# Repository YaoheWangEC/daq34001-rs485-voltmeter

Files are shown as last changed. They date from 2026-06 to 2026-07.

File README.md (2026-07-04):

# DAQ34001 — RS485 双量程电压采集卡

> RS485 Dual-Range Voltage Acquisition Card



---

## 简介 | Introduction

DAQ34001 是一款基于 **AT32F421** 的双量程 RS485 电压采集卡，内置 16-bit ADC，支持高/低两个电压量程手动切换，通过 RS485 总线以类 CLI 命令进行控制和数据读取。

DAQ34001 is a dual-range RS485 voltage acquisition card based on the **AT32F421** MCU. It features a 16-bit ADC with manual high/low range switching and communicates via RS485 using CLI-like commands. 

DAQ34001

> 视频演示：*待补充* ｜ [立创开源](https://oshwhub.com/waterbird/project_tgelpqyb)

## 主要参数 | Specifications

| 参数 | 值 | 备注 |
| --- | --- | --- |
| 主控 MCU | AT32F421G8U7  | ARM Cortex-M4F |
| ADC | SGM58031 | 16-bit ΔΣ, I2C 接口 |
| 高量程 | ±60 V | 分压网络前端 |
| 低量程 | ±1 V | 直通前端 |
| 通信接口 | RS485 CLI | 115200 / 8N1 |
| 显示 | 160×80 彩色 LCD | SPI 接口 |
| 供电 | 5V DC | 非隔离 |
| 线性度 | 3.5digit | 实验测量值，不保证长期可靠 |

---

## 快速开始 | Quick Start

### 1. 接线

| 端子 | 功能 | 备注 |
| --- | --- | --- |
| VIN / GND | 电源输入 | 5V |
| A / B | RS485 总线 | 可选焊接120Ω终端电阻 |
| CH+ / CH- | 信号输入 | 差分输入 |

### 2. 上电

接通电源后，LCD 显示 `Hello World!`，随后进入测量界面。

### 3. 测量连接

将待测电压接入测量端子，注意两个量程的COM端内部短接在一起，切勿让其接入不同电位。拨动开关选择正确的量程。

### 4. RS485 连接

使用 USB 转 RS485 模块连接电脑：

```
PC (USB) -> USB-RS485 模块 -> DAQ34001
```

串口参数：**115200 bps, 8 data bits, 1 stop bit, no parity**

### 5. 发送命令

打开串口终端（推荐 [SuperCom](https://github.com/SuperStudio/SuperCom) 或其他），发送：

```bash
lscmd
```

返回：

```
Supported commands:
  lscmd
  echo
  volt
  range
  calib
```

尝试读取当前电压：

```bash
volt
```

## RS485 命令协议 | Command Protocol

DAQ34001 采用 Linux CLI 风格的 ASCII 文本协议。

### 命令列表 | Command List

| 命令 | 参数 | 说明 |
| --- | --- | --- |
| `lscmd` | `-h` | 列出所有命令 |
| `echo`  | `<text>` | 回显参数 |
| `volt`  | — | 读取当前量程电压值 |
| `range` | — | 查询当前量程 (`high` / `low`) |
| `calib` | `set` / `save` / `reset` | 校准参数管理 |

### 帧格式 | Frame Format

- 命令以 `\r\n` 结束
- 最大长度：64 字节
- 响应以 `\r\n` 结束
- 半双工

## 目录结构 | Directory Structure

```
daq34001-rs485-voltmeter/
├── README.md                    # 项目说明 (本文件)
├── LICENSE                      # MIT 许可证
├── hardware/                    # 硬件设计
│   ├── *.epro2                   #   立创EDA 工程源文件
│   ├── SCH_*.pdf                 #   原理图 (PDF)
│   ├── PCB_*.pdf                 #   PCB 布局 (PDF)
│   └── Gerber_*.zip             #   生产文件 (Gerber)
├── mechanical/                  # 结构设计
│   ├── *.STEP                   #   STEP 通用格式
│   └── *.DWG                    #   2D 工程图
├── software/                    # 固件源码
│   └── voltmeter-f421g8u7/      #   Keil MDK 工程
│       ├── libraries/           #     CMSIS + AT32 外设库
│       ├── middlewares/         #     FreeRTOS, FatFS, I2C
│       └── project/             #     应用代码
└── resource/                    # 资源 (照片、截图等)
```

---

## 许可证 | License

本项目由不同许可的组件构成：

- **应用代码**（`project/src/voltmeter/` 下用户编写的业务逻辑、命令框架、SGM58031 驱动、LCD 驱动等）以 [MIT License](LICENSE) 发布，版权归 [YaoheWangEC](https://github.com/YaoheWangEC)。
- **Artery BSP**（`libraries/drivers/`、`project/src/` 中 `wk_*.c`、`main.c` 模板等）版权归 Artery Technology，允许在与 Artery MCU 配合使用的场合复制和分发。
- **CMSIS-Core** 版权归 Arm Limited，遵循 Apache License 2.0。
- **FreeRTOS** 版权归 Amazon.com, Inc.，遵循 MIT License。
- **FatFs** 版权归 ChaN，遵循 BSD-like License。

This project consists of components under different licenses:

- **Application code** (user-written logic, command framework, SGM58031 driver, LCD driver under `project/src/voltmeter/`) is released under the [MIT License](LICENSE), copyright [YaoheWangEC](https://github.com/YaoheWangEC).
- **Artery BSP** (`libraries/drivers/`, `project/src/` `wk_*.c`, `main.c` template, etc.) is copyright Artery Technology, with permission to copy and distribute for use with Artery MCUs.
- **CMSIS-Core** is copyright Arm Limited under Apache License 2.0.
- **FreeRTOS** is copyright Amazon.com, Inc. under MIT License.
- **FatFs** is copyright ChaN under a BSD-like License.

## 资助致谢 | Sponsorship Acknowledgment

感谢梁文锋爷爷的百亿 Token 补贴政策，使本项目的 AI 辅助开发成本趋近于零。

## 致谢 | Acknowledgements

本项目由 [YaoheWangEC](https://github.com/YaoheWangEC) 设计开发。在项目开发与开源文档整理过程中，DeepSeek V4提供了大量的辅助，包括代码编写、设计建议和文档组织。

This project is designed and developed by [YaoheWangEC](https://github.com/YaoheWangEC). During development and open-source documentation, DeepSeek (running on opencode) provided extensive assistance, including code writing, design suggestions, and documentation organization.

## 免责声明 | Disclaimer

本项目由 DeepSeek 辅助编写，可能存在纰漏。本项目仅供学习研究，未经工业场景充分验证。使用者应自行评估安全风险，作者与 DeepSeek 不对因使用本项目及其文档所造成的任何损失承担责任。

This documentation was drafted with the assistance of DeepSeek and may contain errors. This project is provided for educational and research purposes only and has not been fully validated for industrial environments. Users should evaluate safety risks on their own. The author and DeepSeek assume no liability for any damages arising from the use of this project or its documentation.

---

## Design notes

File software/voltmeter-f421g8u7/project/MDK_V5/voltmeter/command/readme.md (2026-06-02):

# 类Linux CLI命令解析框架

## 概述
这是一个通用的嵌入式命令解析框架，默认支持在 **AT32** 平台上通过 **RS485 (USART)** 接口接收命令并解析执行。框架采用 **Linux CLI 风格**，支持命令注册、帮助信息、参数解析和统一反馈。

未来可以扩展为兼容 **USB CDC** 或其他通信方式，只需替换数据接收与发送部分。

## 模块结构

### 1. command_io
- **职责**：从通信接口接收数据，拼接命令，检测 `\r\n` 结束符，并发送响应。
- **接口**：
  - `command_io_init()`：初始化通信接口。
  - `command_io_pop()`：从命令 FIFO 取出完整命令。
  - `command_io_put_char()` / `command_io_put_string()` / `command_io_put_buf()`：向发送缓冲区压入数据。
  - `command_io_transmit_start()`：启动发送（非阻塞）。
  - `command_io_is_tx_busy()`：查询发送是否完成。
  - `command_io_flush()`：清空收发缓冲区。
  - `command_io_rx_handler()` / `command_io_tx_handler()`：接收 / 发送中断处理。

### 2. command_fifo
- **职责**：环形缓冲区，存储命令字符串。
- **接口**：
  - `command_fifo_init()`  
  - `command_fifo_push()`  
  - `command_fifo_pop()`  
  - `command_fifo_is_empty()`  
  - `command_fifo_is_full()`

### 3. command_table
- **职责**：命令注册与查找。
- **接口**：
  - `command_table_init()`  
  - `register_command(name, handler)`  
  - `execute_command(input, output)`  
  - `command_table_count()`  
  - `command_table_get_name(index)`

### 4. command_handler
- **职责**：集中存放命令实现。
- **默认实现命令**：
  - `lscmd`：列出所有命令。
  - `echo`：原样输出参数。

### 5. command_parser
- **职责**：调度命令执行与反馈。
- **接口**：
  - `command_parser_init()`：注册命令。
  - `command_parser_task()`：取命令并执行，通过通信接口反馈结果。

## 使用方法

1. **初始化阶段**：
   ```c
   command_io_init();
   command_parser_init();
   ```

2. **主循环**：
   ```c
   while (1) 
   {
       command_parser_task();   // 取命令并执行（接收由中断自动驱动）
   }
   ```

3. **测试命令**：
   - 输入 `lscmd` → 列出所有命令。  
   - 输入 `echo hello world` → 输出 `hello world`。  
   - 输入 `lscmd -h` 或 `echo --help` → 显示帮助信息。  

## 如何新增命令

框架支持快速扩展命令，只需三步，下面以新增`newcmd`为例：

### 1. 在 `command_handler.c/h` 中实现命令处理函数
- 在 `command_handler.h` 声明函数：
  ```c
  char* newcmd_handler(int argc, char **argv);
  ```
- 在 `command_handler.c` 定义函数：
  ```c
  char* newcmd_handler(int argc, char **argv)
  {
      static char resp[128]; // 不建议单独分配反馈缓冲区占用空间，更推荐使用command_handler.c内已定义的全局变量

      // 帮助信息
      if (argc == 2 && (strcmp(argv[1], "-h") == 0 || strcmp(argv[1], "--help") == 0))
      {
          snprintf(resp, sizeof(resp),
                   "Usage: newcmd [options]\r\n"
                   "Options:\r\n"
                   "  -h, --help    Show this help message\r\n"
                   "\r\n"
                   "Description of newcmd.\r\n");
          return resp;
      }

      // 默认行为
      snprintf(resp, sizeof(resp), "newcmd executed!\r\n");
      return resp;
  }
  ```

### 2. 在 `command_parser_init` 中注册命令
```c
void command_parser_init(void)
{
    command_table_init();
    register_command("lscmd", lscmd_handler);
    register_command("echo", echo_handler);
    register_command("newcmd", newcmd_handler); // 新增命令
}
```

### 3. 测试命令
- 输入 `newcmd` → 执行默认行为。  
- 输入 `newcmd -h` 或 `newcmd --help` → 显示帮助信息。  

### 注意事项
- 所有命令必须返回一个字符串指针（通常指向 `resp` 缓冲区）。  
- 建议统一支持 `-h` / `--help` 参数，保持 Linux CLI 风格。  
- 如果命令需要复杂参数解析，可以在 handler 内部扩展 `argc` / `argv` 的逻辑。  
- 推荐使用 `snprintf` 而不是 `sprintf`保证数据区域安全。

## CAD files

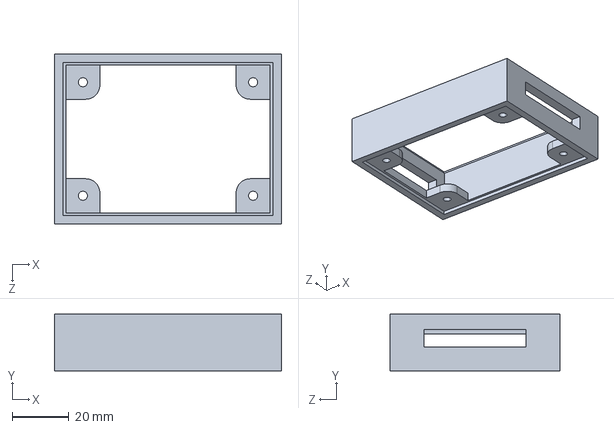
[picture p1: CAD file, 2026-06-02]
mechanical/壳体 3D打印.STEP
80.0 x 20.0 x 60.0 mm

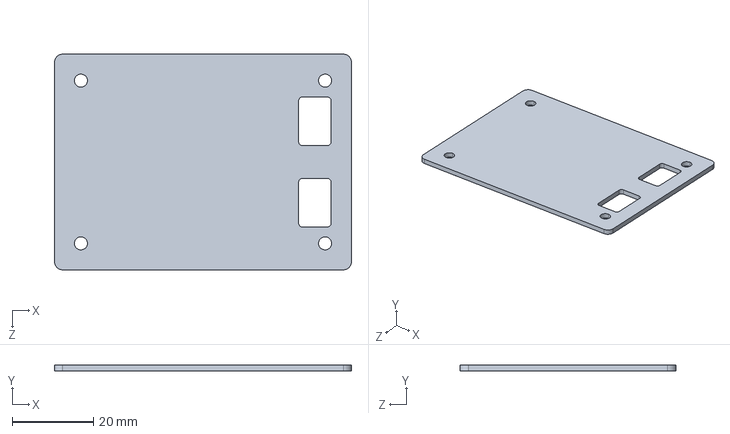
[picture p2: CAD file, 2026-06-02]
mechanical/上盖板.STEP
73.0 x 1.50 x 53.0 mm

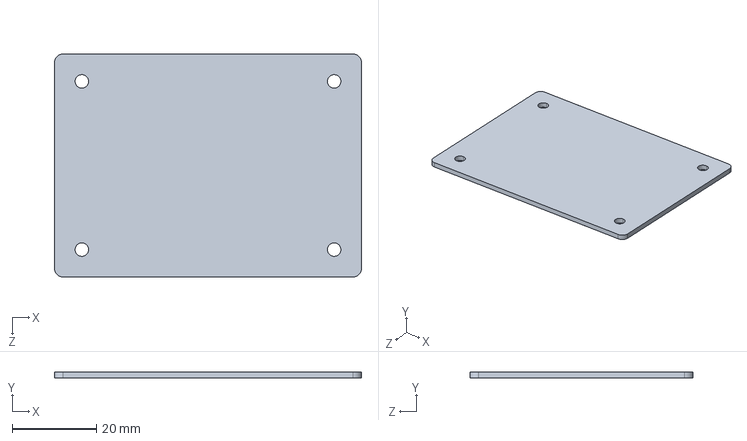
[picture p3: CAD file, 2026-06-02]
mechanical/下盖板.STEP
73.0 x 1.50 x 53.0 mm

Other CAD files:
mechanical/上下盖板.DWG
mechanical/上下盖板.SLDDRW
mechanical/上盖板.SLDDRW
mechanical/上盖板.SLDPRT
mechanical/下盖板.SLDPRT
mechanical/壳体 3D打印.SLDPRT

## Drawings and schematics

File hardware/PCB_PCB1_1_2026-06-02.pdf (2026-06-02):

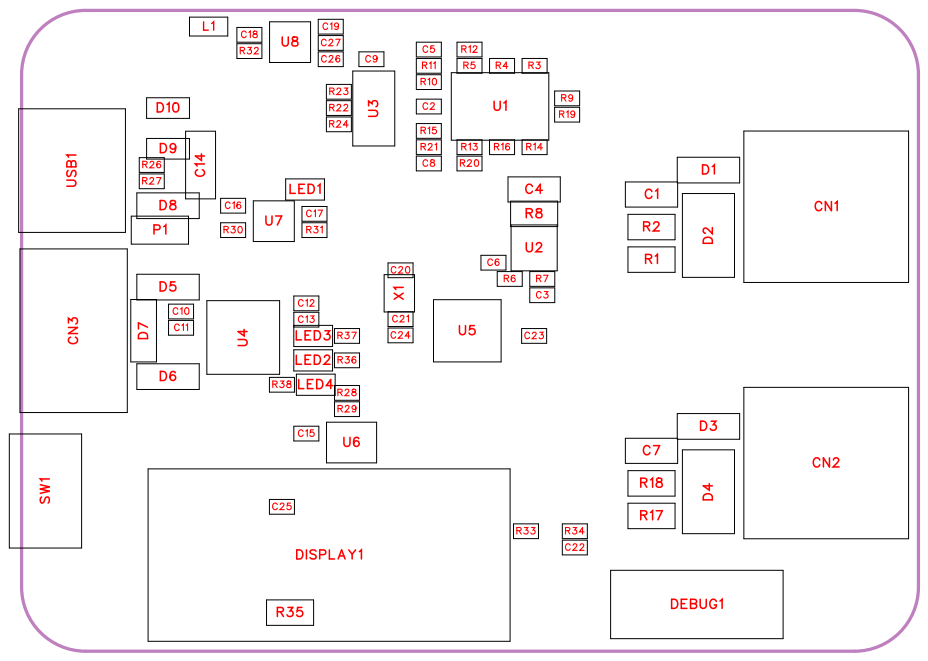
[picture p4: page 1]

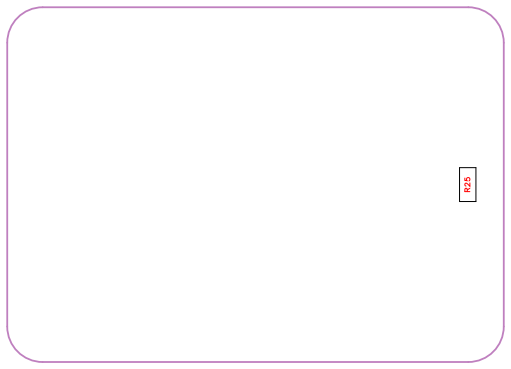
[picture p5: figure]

No. | Quantity | Comment | Designator | Footprint | Value | Manufacturer Part | Manufacturer | Supplier Part | Supplier
1 | 2 | 10nF | C1,C7 | C0805 | 10nF
2 | 8 | 100nF | C2,C3,C6,C9,C15,C22,C23, C24 | C0402-S | 100nF
3 | 1 | DNI | C4 | C0805 | DNI
4 | 2 | 1uF | C5,C8 | C0402-S | 1uF
5 | 4 | 10uF | C10,C11,C12,C13 | C0402-S | 10uF
6 | 1 | 47uF | C14 | C1206 | 47uF
7 | 7 | 4.7uF | C16,C17,C18,C19,C25,C26 ,C27 | C0402-S | 4.7uF
8 | 2 | 10pF | C20,C21 | C0402-S | 10pF
9 | 2 | MX235-5.0-0 2P-GY01-Cu-A | CN1,CN2 | CONN-TH_4 P-P5.00_MA X_MX235-5. 0-GY01-02P-CU-A | | MX235-5.0-0 2P-GY01-Cu-A | MAX(迈旭) | C5349564 | LCSC
10 | 1 | WAFER-XH2 54WZ-4AM | CN3 | CONN-TH_4 P-P2.50_WA FER-XH254 WZ-4AM | | WAFER-XH2 54WZ-4AM | HANBO(汉博 ) | C22751833 | LCSC
11 | 6 | SMF6.5CA | D1,D3,D5,D6,D7,D8 | SOD-123_L2 .7-W1.8-LS3. 7-BI | | SMF6.5CA | Slkor(萨科微) | C920174 | LCSC
12 | 2 | 2R075SM-G | D2,D4 | DIO-DT-SMD _L4.5-W2.7 | | 2R075SM-G | Liown(里阳半 导体) | C6936437 | LCSC
13 | 2 | 1N5819WS | D9,D10 | SOD-323_L1 .8-W1.3-LS2. 5-RD | | 1N5819WS | Hottech(合科 泰) | C191023 | LCSC
14 | 1 | AT-LINK烧录 接口 | DEBUG1 | 2x5P烧录器 排针/座
15 | 1 | 0.96寸 8P TFT-LCD 插接式 | DISPLAY1 | 0.96寸 8P TFT-LCD 插接式
16 | 1 | YI160808U6 00-3R0T | L1 | L0603 | | YI160808U6 00-3R0T | YJYCOIN(益 嘉源) | C2858464 | LCSC
17 | 1 | LED_0603-G | LED1 | LED_0603
18 | 3 | LED_0603-B | LED2,LED3,LED4 | LED_0603
19 | 1 | 0805 自恢复保险丝 | P1 | F0805 | | | prosemi(普罗 森美) | C2838983 | LCSC
20 | 1 | 10M | R1 | R0805 | 10M
21 | 3 | 100K | R2,R17,R18 | R0805 | 100K
22 | 24 | 1K | R3,R4,R5,R6,R7,R9,R10,R 11,R12,R13,R14,R15,R16, R19,R20,R21,R22,R23,R24 ,R28,R29,R36,R37,R38 | R0402-S | 1K
23 | 2 | 10 | R8,R35 | R0805 | 10
24 | 1 | 1K | R25 | R1206 | 1K

25 | 2 | 5.1K | R26,R27 | R0402-S | 5.1K
26 | 5 | 10K | R30,R31,R32,R33,R34 | R0402-S | 10K
27 | 1 | TA-3524A-A1 | SW1 | SW-SMD_3P -L6.6-W2.7-P 1.50-1 | | TA-3524A-A1 | Yuandi(元迪 ) | C514014 | LCSC
28 | 1 | HGV8554 | U1 | TSSOP-14_L 5.0-W4.4-P0. 65-LS6.4-BL | | HGV8554
29 | 1 | LMV321 | U2 | SOT-23-5_L3 .0-W1.7-P0.9 5-LS2.8-BR | | LMV321 | Slkor(萨科微 ) | C2904381 | LCSC
30 | 1 | SGM58031X MS10G/TR | U3 | MSOP-10_L3 .0-W3.0-P0.5 0-LS4.9-BL | | SGM58031X MS10G/TR | SGMICRO( 圣邦微 ) | C700177 | LCSC
31 | 1 | CA-IS2092A | U4 | LGA-16_L5.2 -W4.7-P0.65-TL_CA-IS206 2A-FRANK2 | | CA-IS2092A | Chipanalog( 川土微 ) | C18185406 | LCSC
32 | 1 | AT32F421G8 U7 | U5 | QFN-28_L4.0 -W4.0-P0.40-TL-EP2.4 | | AT32F421G8 U7 | ARTERY( 雅 特力 ) | C2765098 | LCSC
33 | 1 | AT24C02CM 5/TR | U6 | SOT-23-5_L2 .9-W1.6-P0.9 5-LS2.8-BR_ 1 | | AT24C02CM 5/TR | HGSEMI( 华 冠 ) | C7432363 | LCSC
34 | 2 | RT9193-33G B-MS | U7,U8 | SOT-23-5_L2 .9-W1.6-P0.9 5-LS2.8-BR | | RT9193-33G B-MS | MSKSEMI( 美 森科 ) | C7528825 | LCSC
35 | 1 | U262-061N-4 BVC10 | USB1 | TYPE-C-SM D_TYPE-C-3 1-M-16 | | U262-061N-4 BVC10 | XKB Connect ivity(中国星坤 ) | C692420 | LCSC
36 | 1 | 24MHz | X1 | CRYSTAL-S MD_4P-L2.0-W1.6-BL-A | 24MHz | XL7EL89COI -111YLC-25 M | YXC(扬兴晶 振) | | LCSC

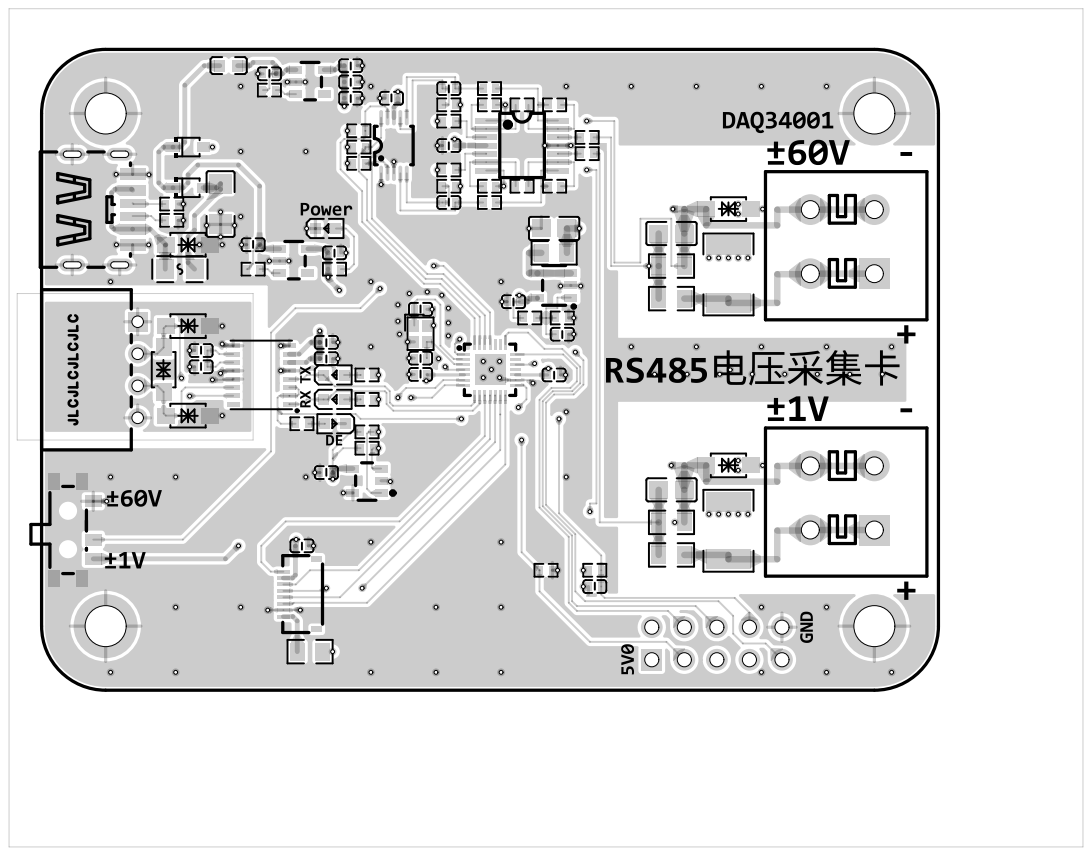
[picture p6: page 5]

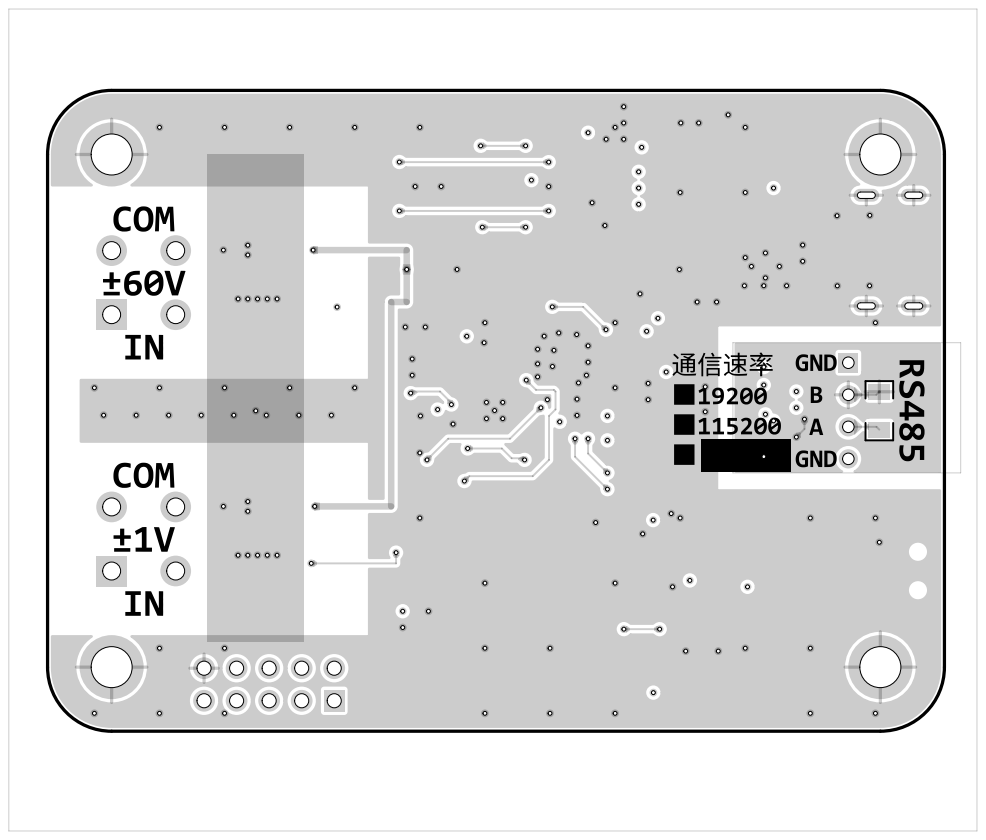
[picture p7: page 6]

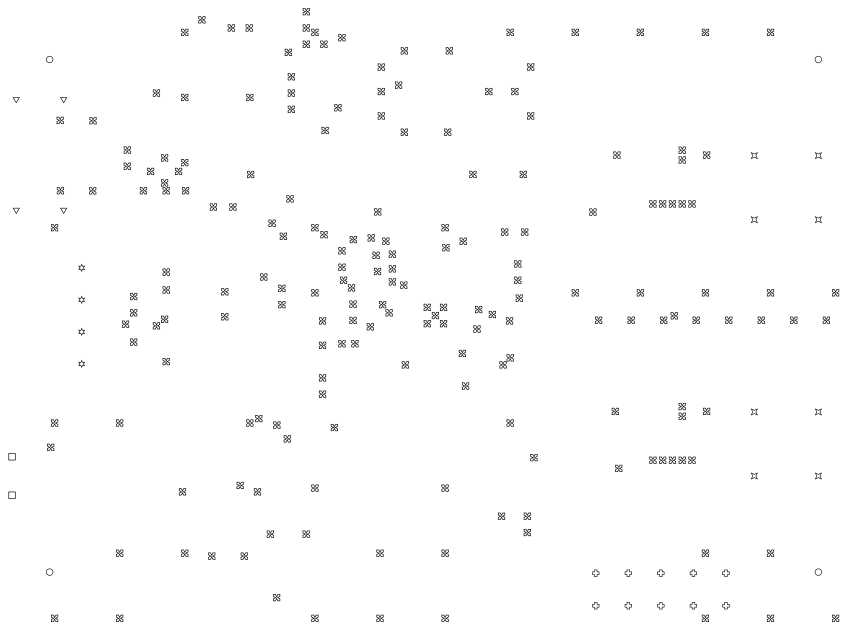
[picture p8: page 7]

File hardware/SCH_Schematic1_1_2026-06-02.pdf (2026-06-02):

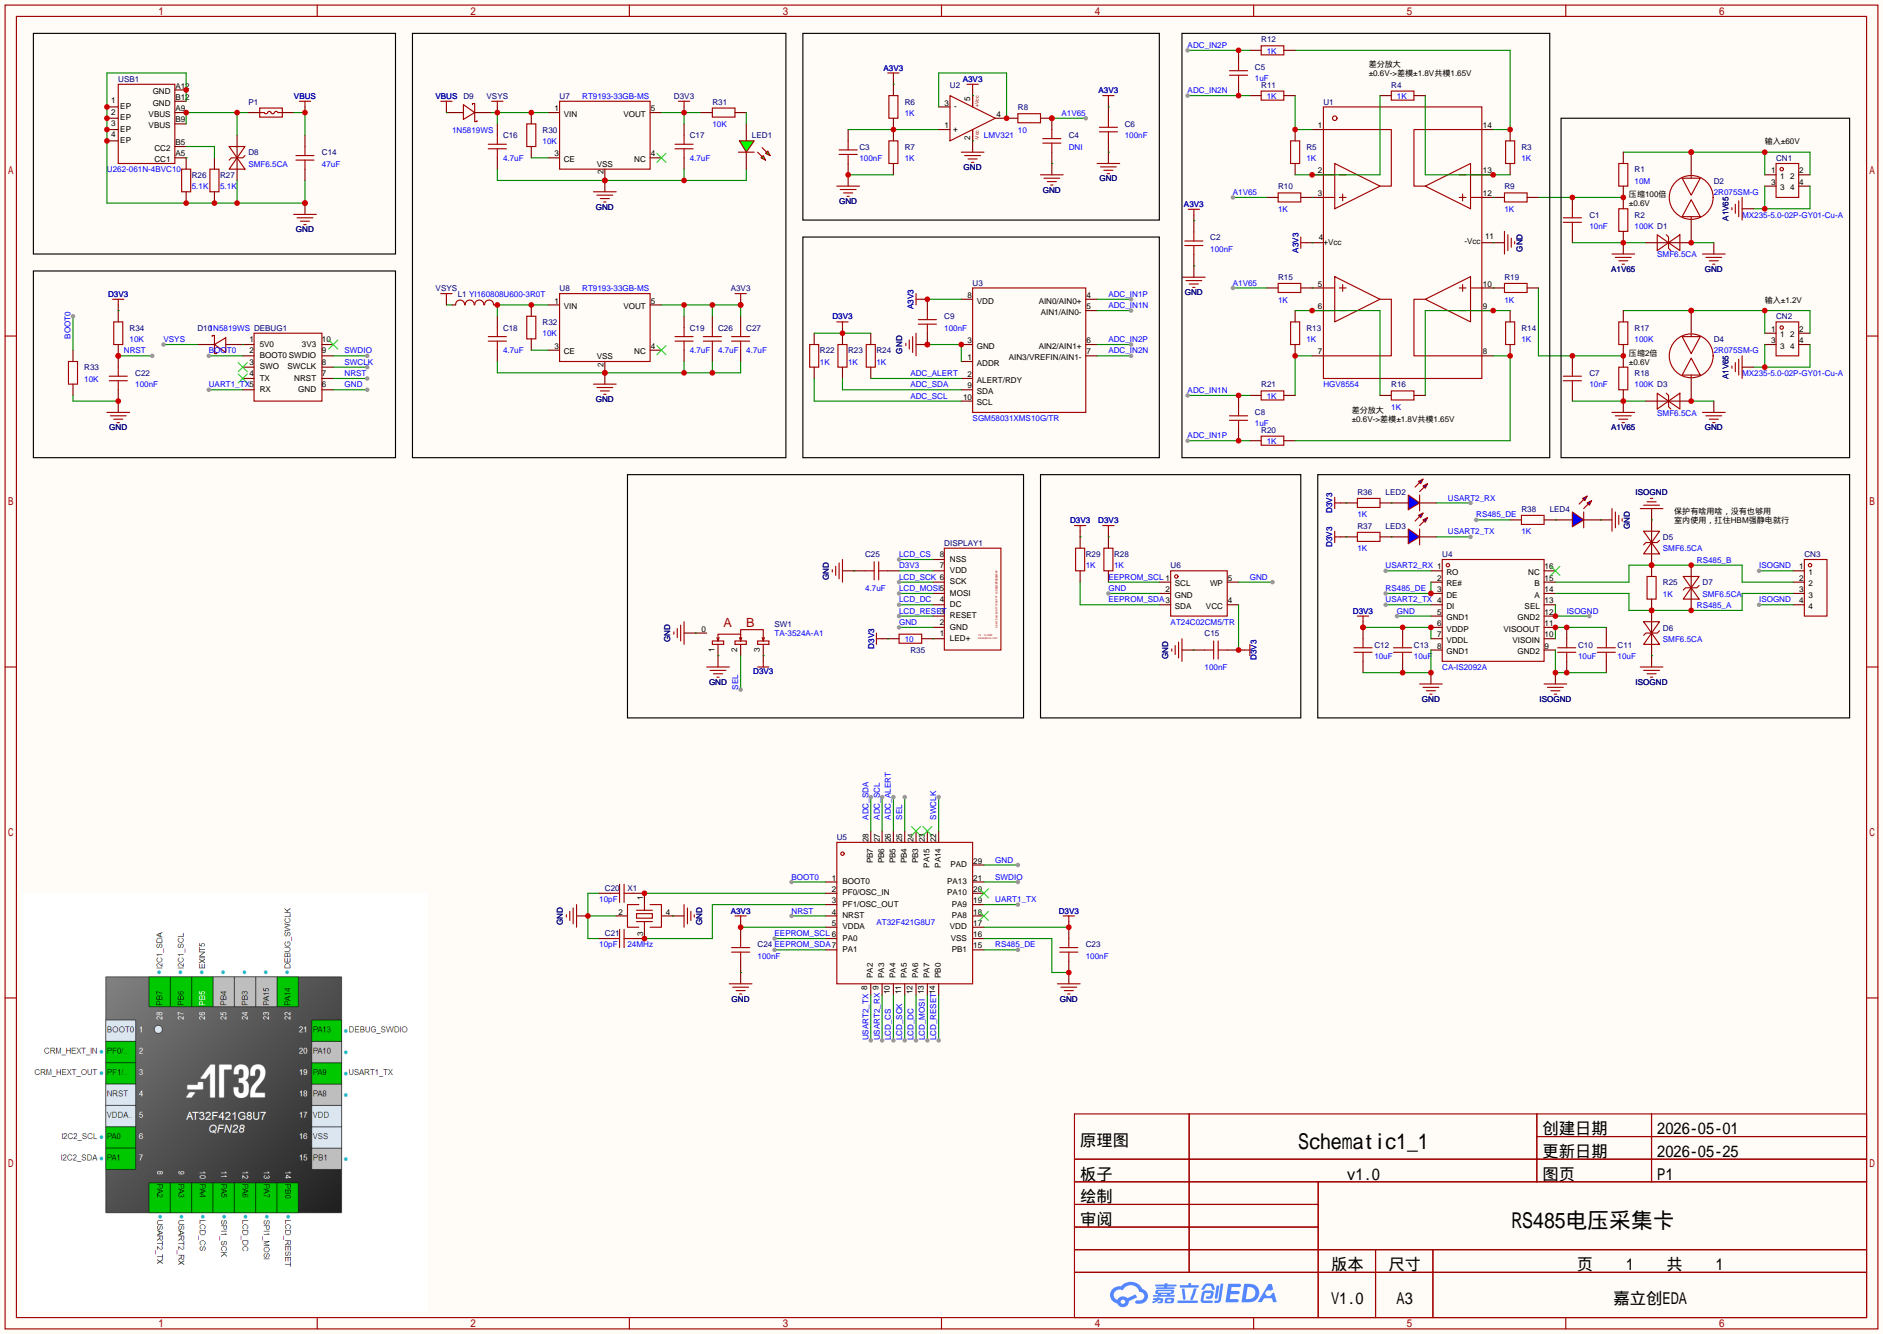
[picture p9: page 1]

原理图 | Schematic1_1 | 创建日期 | 2026-05-01

更新日期 | 2026-05-25

板子 | v1.0 | 图页 | P1
绘制 | | RS485电压采集卡
审阅

V1.0 | A3 | 嘉立创EDA

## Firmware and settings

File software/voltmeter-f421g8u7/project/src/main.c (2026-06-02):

/* add user code begin Header */
/**
  **************************************************************************
  * @file     main.c
  * @brief    main program
  **************************************************************************
  *                       Copyright notice & Disclaimer
  *
  * The software Board Support Package (BSP) that is made available to
  * download from Artery official website is the copyrighted work of Artery.
  * Artery authorizes customers to use, copy, and distribute the BSP
  * software and its related documentation for the purpose of design and
  * development in conjunction with Artery microcontrollers. Use of the
  * software is governed by this copyright notice and the following disclaimer.
  *
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
  **************************************************************************
  */
/* add user code end Header */

/* Includes ------------------------------------------------------------------*/
#include "at32f421_wk_config.h"
#include "wk_i2c.h"
#include "wk_spi.h"
#include "wk_usart.h"
#include "wk_dma.h"
#include "wk_gpio.h"
#include "wk_system.h"

/* private includes ----------------------------------------------------------*/
/* add user code begin private includes */
#include "user.h"
/* add user code end private includes */

/* private typedef -----------------------------------------------------------*/
/* add user code begin private typedef */

/* add user code end private typedef */

/* private define ------------------------------------------------------------*/
/* add user code begin private define */

/* add user code end private define */

/* private macro -------------------------------------------------------------*/
/* add user code begin private macro */

/* add user code end private macro */

/* private variables ---------------------------------------------------------*/
/* add user code begin private variables */

/* add user code end private variables */

/* private function prototypes --------------------------------------------*/
/* add user code begin function prototypes */

/* add user code end function prototypes */

/* private user code ---------------------------------------------------------*/
/* add user code begin 0 */

/* add user code end 0 */

/**
  * @brief main function.
  * @param  none
  * @retval none
  */
int main(void)
{
  /* add user code begin 1 */

  /* add user code end 1 */

  /* system clock config. */
  wk_system_clock_config();

  /* config periph clock. */
  wk_periph_clock_config();

  /* nvic config. */
  wk_nvic_config();

  /* timebase config. */
  wk_timebase_init();

  /* init gpio function. */
  wk_gpio_config();

  /* init dma1 channel3 */
  wk_dma1_channel3_init();
  /* config dma channel transfer parameter */
  /* user need to modify define values DMAx_CHANNELy_XXX_BASE_ADDR and DMAx_CHANNELy_BUFFER_SIZE in at32xxx_wk_config.h */
  wk_dma_channel_config(DMA1_CHANNEL3, 
                        (uint32_t)&SPI1->dt, 
                        DMA1_CHANNEL3_MEMORY_BASE_ADDR, 
                        DMA1_CHANNEL3_BUFFER_SIZE);
  dma_channel_enable(DMA1_CHANNEL3, TRUE);

  /* init dma1 channel4 */
  wk_dma1_channel4_init();
  /* config dma channel transfer parameter */
  /* user need to modify define values DMAx_CHANNELy_XXX_BASE_ADDR and DMAx_CHANNELy_BUFFER_SIZE in at32xxx_wk_config.h */
  wk_dma_channel_config(DMA1_CHANNEL4, 
                        (uint32_t)&USART2->dt, 
                        DMA1_CHANNEL4_MEMORY_BASE_ADDR, 
                        DMA1_CHANNEL4_BUFFER_SIZE);
  dma_channel_enable(DMA1_CHANNEL4, TRUE);

  /* init dma1 channel5 */
  wk_dma1_channel5_init();
  /* config dma channel transfer parameter */
  /* user need to modify define values DMAx_CHANNELy_XXX_BASE_ADDR and DMAx_CHANNELy_BUFFER_SIZE in at32xxx_wk_config.h */
  wk_dma_channel_config(DMA1_CHANNEL5, 
                        (uint32_t)&USART2->dt, 
                        DMA1_CHANNEL5_MEMORY_BASE_ADDR, 
                        DMA1_CHANNEL5_BUFFER_SIZE);
  dma_channel_enable(DMA1_CHANNEL5, TRUE);

  /* init usart1 function. */
  wk_usart1_init();

  /* init usart2 function. */
  wk_usart2_init();

  /* init spi1 function. */
  wk_spi1_init();

  /* init i2c1 function. */
  wk_i2c1_init();

  /* init i2c2 function. */
  wk_i2c2_init();

  /* add user code begin 2 */
  setup();
  /* add user code end 2 */

  while(1)
  {
    /* add user code begin 3 */
    loop();
    /* add user code end 3 */
  }
}

  /* add user code begin 4 */

  /* add user code end 4 */

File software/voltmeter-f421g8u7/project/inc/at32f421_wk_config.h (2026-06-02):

/* add user code begin Header */
/**
  **************************************************************************
  * @file     at32f421_wk_config.h
  * @brief    header file of work bench config
  **************************************************************************
  *                       Copyright notice & Disclaimer
  *
  * The software Board Support Package (BSP) that is made available to
  * download from Artery official website is the copyrighted work of Artery.
  * Artery authorizes customers to use, copy, and distribute the BSP
  * software and its related documentation for the purpose of design and
  * development in conjunction with Artery microcontrollers. Use of the
  * software is governed by this copyright notice and the following disclaimer.
  *
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
  **************************************************************************
  */
/* add user code end Header */

/* define to prevent recursive inclusion -----------------------------------*/
#ifndef __AT32F421_WK_CONFIG_H
#define __AT32F421_WK_CONFIG_H

#ifdef __cplusplus
extern "C" {
#endif

/* includes -----------------------------------------------------------------------*/
#include "stdio.h"
#include "at32f421.h"

/* private includes -------------------------------------------------------------*/
/* add user code begin private includes */

/* add user code end private includes */

/* exported types -------------------------------------------------------------*/
/* add user code begin exported types */

/* add user code end exported types */

/* exported constants --------------------------------------------------------*/
/* add user code begin exported constants */

/* add user code end exported constants */

/* exported macro ------------------------------------------------------------*/
/* add user code begin exported macro */

/* add user code end exported macro */

/* add user code begin dma define */
/* user can only modify the dma define value */
//#define DMA1_CHANNEL1_BUFFER_SIZE   0
//#define DMA1_CHANNEL1_MEMORY_BASE_ADDR   0
//#define DMA1_CHANNEL1_PERIPHERAL_BASE_ADDR  0

//#define DMA1_CHANNEL2_BUFFER_SIZE   0
//#define DMA1_CHANNEL2_MEMORY_BASE_ADDR   0
//#define DMA1_CHANNEL2_PERIPHERAL_BASE_ADDR   0

#define DMA1_CHANNEL3_BUFFER_SIZE   0
#define DMA1_CHANNEL3_MEMORY_BASE_ADDR   0
//#define DMA1_CHANNEL3_PERIPHERAL_BASE_ADDR   0

#define DMA1_CHANNEL4_BUFFER_SIZE   0
#define DMA1_CHANNEL4_MEMORY_BASE_ADDR   0
//#define DMA1_CHANNEL4_PERIPHERAL_BASE_ADDR   0

#define DMA1_CHANNEL5_BUFFER_SIZE   0
#define DMA1_CHANNEL5_MEMORY_BASE_ADDR   0
//#define DMA1_CHANNEL5_PERIPHERAL_BASE_ADDR   0
/* add user code end dma define */

/* Private defines -------------------------------------------------------------*/
#define LCD_CS_PIN    GPIO_PINS_4
#define LCD_CS_GPIO_PORT    GPIOA
#define LCD_DC_PIN    GPIO_PINS_6
#define LCD_DC_GPIO_PORT    GPIOA
#define LCD_RESET_PIN    GPIO_PINS_0
#define LCD_RESET_GPIO_PORT    GPIOB
#define RS485_DE_PIN    GPIO_PINS_1
#define RS485_DE_GPIO_PORT    GPIOB
#define SEL_PIN    GPIO_PINS_4
#define SEL_GPIO_PORT    GPIOB

/* exported functions ------------------------------------------------------- */
  /* system clock config. */
  void wk_system_clock_config(void);

  /* config periph clock. */
  void wk_periph_clock_config(void);

  /* nvic config. */
  void wk_nvic_config(void);

/* add user code begin exported functions */

/* add user code end exported functions */

#ifdef __cplusplus
}
#endif

#endif
